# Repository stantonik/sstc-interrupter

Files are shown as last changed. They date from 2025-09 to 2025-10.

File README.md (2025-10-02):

# SSTC-Interrupter

> Digital interrupter for driving SSTC/DRSSTC Tesla coils, built around the ESP32-S3.
Easily customizable and extensible thanks to the microcontroller platform.

**Actually in development!**

## Overview

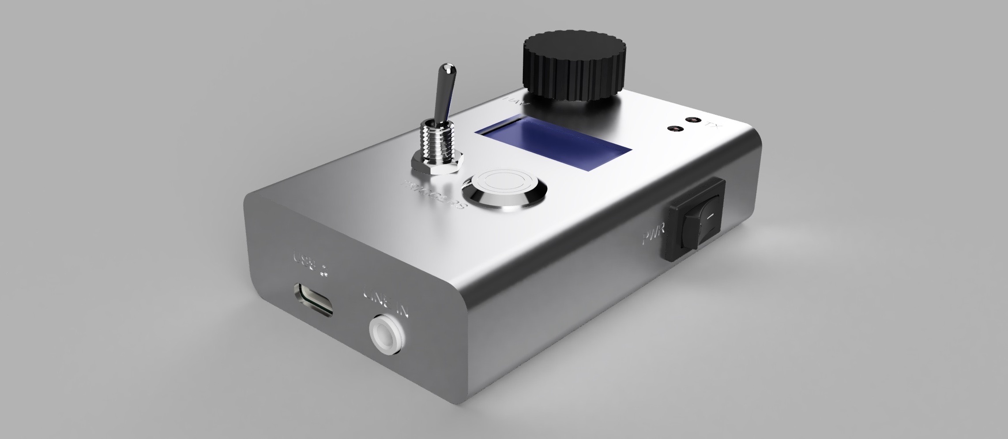
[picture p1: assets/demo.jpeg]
demo


This project implements a digital interrupter for Solid State Tesla Coils (SSTC) or Dual-Resonant SSTCs (DRSSTC). The interrupter allows precise control over the arc output using different control modes, making it easy to experiment with pulse timing, audio modulation, or MIDI control.

## Hardware Highlights

- Microcontroller: ESP32-S3 - powerful, friendly SDK, and USB-OTG.
- Isolation: Fiber-optic input using TOSLINK transceivers. Safe and affordable alternative to Broadcom HFBR14xx/24xx.
- Cost-effective: Total BOM under 20 €, including ESP32-S3, TOSLINK modules, and basic passive components.
- User interface: 164×64 OLED screen (running LVGL) with rotary encoder.
- Connectivity:
  - 3.5 mm line-in for audio modulation.
  - USB-OTG (serial, MIDI, ...)
  - TOSLINK/pin header outputs

## Features

**1. Manual Mode**

- Control three parameters directly using knobs:
  - Pulse Duration (PD) – width of each pulse.
  - Pulse Repetition Frequency (PRF) – pulse frequency.
  - Power – proportional to PD.
- Generates PWM signals from 1 Hz up to 20 kHz with a minimum pulse width of 1 µs.
- Ideal for manual experimentation and tuning the arc.WM carrier frequency is 30KHz by default, but you can adjust these value to fit your needs.

The signal generated is supposed to be ANDed with your main Tesla drive signal.

**2. Audio (Line-In) Mode**

- Connect any audio source via a 3.5 mm jack.
- Audio is sampled at 16 kHz and used to modulate the PWM output.
- Default PWM carrier frequency is 30 kHz, adjustable to match your Tesla coil system.
- Supports basic PWM modulation for now, but can be extended for other modulation schemes.

**3. MIDI Mode**

- Connect a MIDI device to control the arc in real time.
- Map MIDI notes to pulse patterns for musical performance with your Tesla coil.

## Notes

- The output of this module is intended to be ANDed with your main Tesla coil drive signal.
- All modes are fully software-driven on the ESP32-S3, making it easy to customize, extend, or add new modulation features.

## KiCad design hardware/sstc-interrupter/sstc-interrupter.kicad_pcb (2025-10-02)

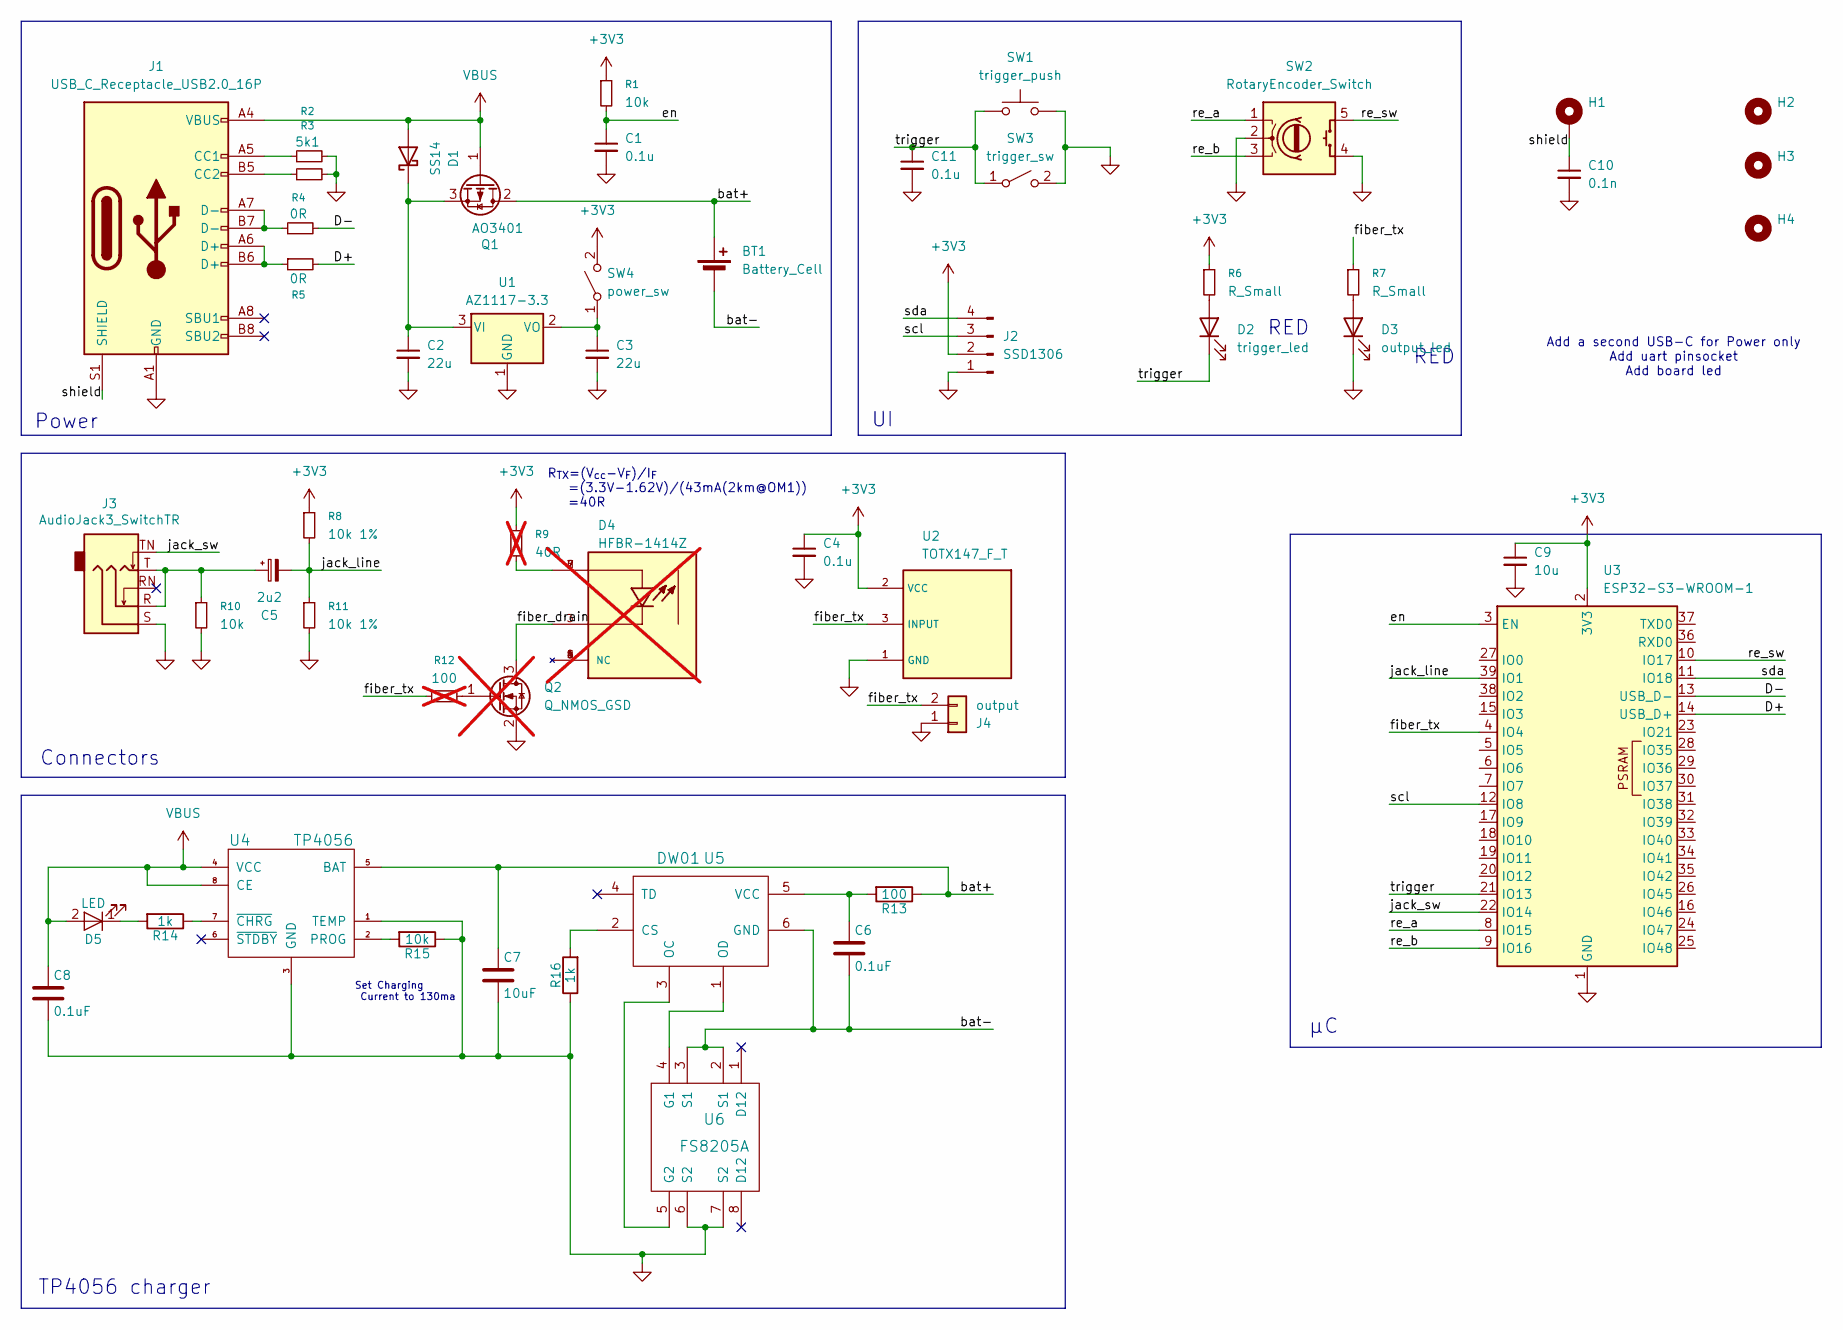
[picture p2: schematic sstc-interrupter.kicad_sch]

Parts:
BT1: Battery_Cell; JST_PH_B2B-PH-K_1x02_P2.00mm_Vertical
C1, C4, C11: 0.1u; C_0603_1608Metric_Pad1.08x0.95mm_HandSolder
C2, C3: 22u; C_0805_2012Metric_Pad1.18x1.45mm_HandSolder
C5: 2u2; C_Radial_D5.0mm_H11.0mm_P2.00mm
C6, C8: 0.1uF; C_0603_1608Metric_Pad1.08x0.95mm_HandSolder
C7: 10uF; C_0603_1608Metric_Pad1.08x0.95mm_HandSolder
C9: 10u; C_0805_2012Metric_Pad1.18x1.45mm_HandSolder
C10: 0.1n; C_0805_2012Metric_Pad1.18x1.45mm_HandSolder
D1: SS14; D_SMA
D2: trigger_led; PinHeader_1x02_P2.54mm_Vertical
D3: output_led; PinHeader_1x02_P2.54mm_Vertical
D4: HFBR-1414Z; OPTO_HFBR-1414Z; PARTREV February 15, 2019; not fitted
D5: LED; LED_0603_1608Metric_Pad1.05x0.95mm_HandSolder
H1: MountingHole_Pad; MountingHole_2.2mm_M2_DIN965_Pad
H2, H3, H4: MountingHole; MountingHole_2.2mm_M2_DIN965
J1: USB_C_Receptacle_USB2.0_16P; USB_C_Receptacle_GCT_USB4105-xx-A_16P_TopMnt_Horizontal
J2: SSD1306; PinHeader_1x04_P2.54mm_Vertical
J3: AudioJack3_SwitchTR; Jack_3.5mm_CUI_SJ1-3525N_Horizontal
J4: output; PinHeader_1x02_P2.54mm_Horizontal
Q1: AO3401; SOT-23_Handsoldering
Q2: Q_NMOS_GSD; SOT-23-3; not fitted
R1, R10, R15: 10k; R_0603_1608Metric_Pad0.98x0.95mm_HandSolder
R2, R3: 5k1; R_0603_1608Metric_Pad0.98x0.95mm_HandSolder
R4, R5: 0R; R_0603_1608Metric_Pad0.98x0.95mm_HandSolder
R6, R7: R_Small; R_0603_1608Metric_Pad0.98x0.95mm_HandSolder
R8, R11: 10k 1%; R_0603_1608Metric_Pad0.98x0.95mm_HandSolder
R9: 40R; R_0603_1608Metric_Pad0.98x0.95mm_HandSolder; not fitted
R12: 100; R_0603_1608Metric_Pad0.98x0.95mm_HandSolder; not fitted
R13: 100; R_0603_1608Metric_Pad0.98x0.95mm_HandSolder
R14, R16: 1k; R_0603_1608Metric_Pad0.98x0.95mm_HandSolder
SW1: trigger_push; PinHeader_1x02_P2.54mm_Vertical
SW2: RotaryEncoder_Switch; PinHeader_1x05_P2.54mm_Vertical
SW3: trigger_sw; PinHeader_1x02_P2.54mm_Vertical
SW4: power_sw; PinHeader_1x02_P2.54mm_Vertical
U1: AZ1117-3.3; SOT-89-3
U2: TOTX147_F_T; TOSHIBA_TORX147_F_T_
U3: ESP32-S3-WROOM-1; ESP32-S3-WROOM-1U
U4: TP4056; SOP-8_3.9x4.9mm_P1.27mm
U5: DW01; SOT-23-6_Handsoldering
U6: FS8205A; TSSOP-8_4.4x3mm_P0.65mm

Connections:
+3V3: C4.1, C9.1, J2.2, R1.1, R6.1, R8.1, R9.1, SW4.2 (B), U2.2 (VCC), U3.2 (3V3)
/D+: R5.2, U3.14 (USB_D+)
/D-: R4.2, U3.13 (USB_D-)
/bat+: BT1.1 (+), C7.1, Q1.2 (D), R13.1, U4.5 (BAT)
/bat-: BT1.2 (-), C6.2, U5.6 (GND), U6.2 (S1), U6.3 (S1)
/en: C1.1, R1.2, U3.3 (EN)
/fiber_tx: J4.2, R7.1, R12.1, U2.3 (INPUT), U3.4 (IO4)
/jack_line: C5.2, R8.2, R11.1, U3.39 (IO1)
/jack_sw: J3.TN, U3.22 (IO14)
/re_a: SW2.1 (A), U3.8 (IO15)
/re_b: SW2.3 (B), U3.9 (IO16)
/re_sw: SW2.5 (S1), U3.10 (IO17)
/scl: J2.3, U3.12 (IO8)
/sda: J2.4, U3.11 (IO18)
/shield: C10.1, H1.1, J1.S1 (SHIELD)
/trigger: C11.1, D2.1 (K), SW1.1, SW3.1 (A), U3.21 (IO13)
GND: C1.2, C2.2, C3.2, C4.2, C7.2, C8.2, C9.2, C10.2, C11.2, D3.1 (K), J1.A1 (GND), J1.A12 (GND), J1.B1 (GND), J1.B12 (GND), J2.1, J3.S, J4.1, Q2.2 (S), R2.2, R3.2, R10.2, R11.2, R15.1, R16.1, SW1.2, SW2.2 (C), SW2.4 (S2), SW3.2 (B), U1.1 (GND), U2.1 (GND), U3.1 (GND), U3.40 (GND), U3.41 (GND), U4.1 (TEMP), U4.3 (GND), U6.6 (S2), U6.7 (S2)
unnamed: C5.1, J3.R, J3.T, R10.1
unnamed: C2.1, D1.1 (K), Q1.3 (S), U1.3 (VI)
unnamed: D2.2 (A), R6.2
unnamed: D3.2 (A), R7.2
unnamed: D4.1 (NC), D4.4 (NC), D4.5 (NC), D4.8 (NC)
unnamed: D4.2, D4.6, D4.7, R9.2
unnamed: D4.3, Q2.3 (D)
unnamed: D5.1 (K), R14.2
unnamed: J1.A5 (CC1), R2.1
unnamed: J1.B5 (CC2), R3.1
unnamed: J1.A6 (D+), J1.B6 (D+), R5.1
unnamed: J1.A7 (D-), J1.B7 (D-), R4.1
unnamed: Q2.1 (G), R12.2
unnamed: C3.1, SW4.1 (A), U1.2 (VO)
unnamed: R15.2, U4.2 (PROG)
unnamed: R14.1, U4.7 (~CHRG)
unnamed: R16.2, U5.2 (CS)
unnamed: U5.3 (OC), U6.5 (G2)
unnamed: U5.1 (OD), U6.4 (G1)
unnamed: C6.1, R13.2, U5.5 (VCC)
VBUS: C8.1, D1.2 (A), D5.2 (A), J1.A4 (VBUS), J1.A9 (VBUS), J1.B4 (VBUS), J1.B9 (VBUS), Q1.1 (G), U4.4 (VCC), U4.8 (CE)

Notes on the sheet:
Add a second USB-C for Power only Add uart pinsocket Add board led
Set Charging Current to 130ma
Connectors
R_{TX}=(V_{cc}-V_{F})/I_{F} =(3.3V-1.62V)/(43mA(2km@OM1)) =40R
RED
Power
TP4056 charger

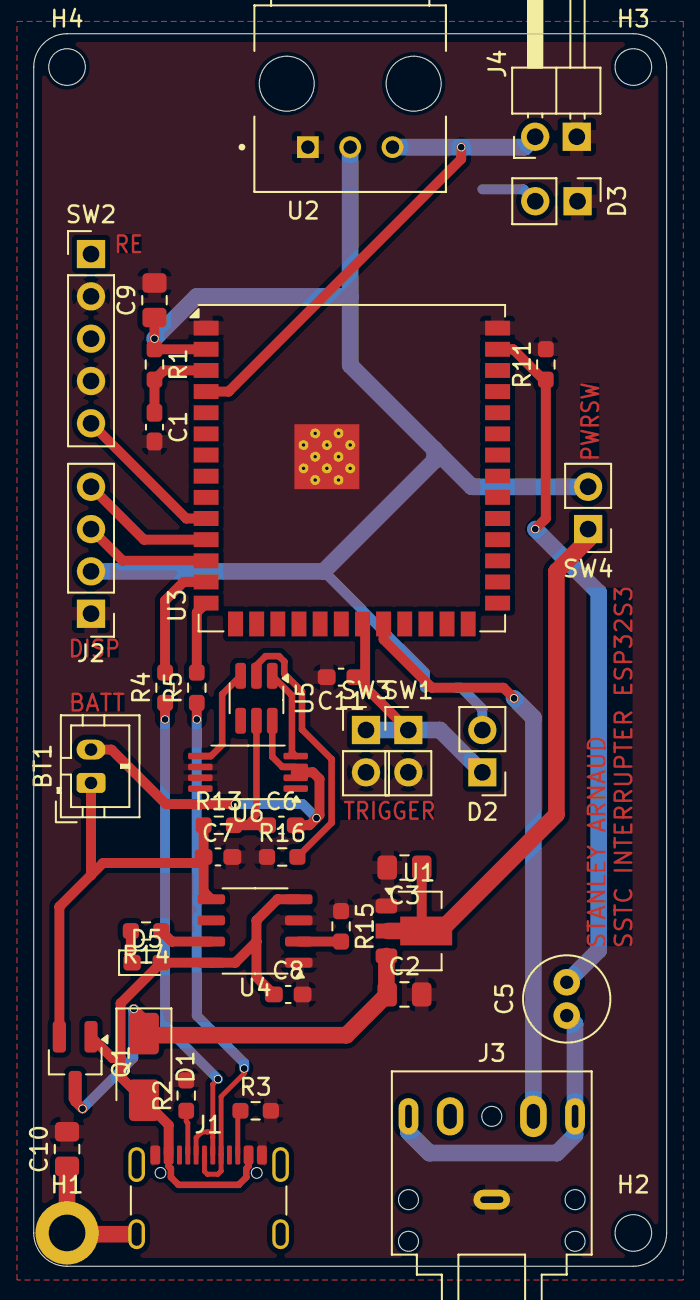
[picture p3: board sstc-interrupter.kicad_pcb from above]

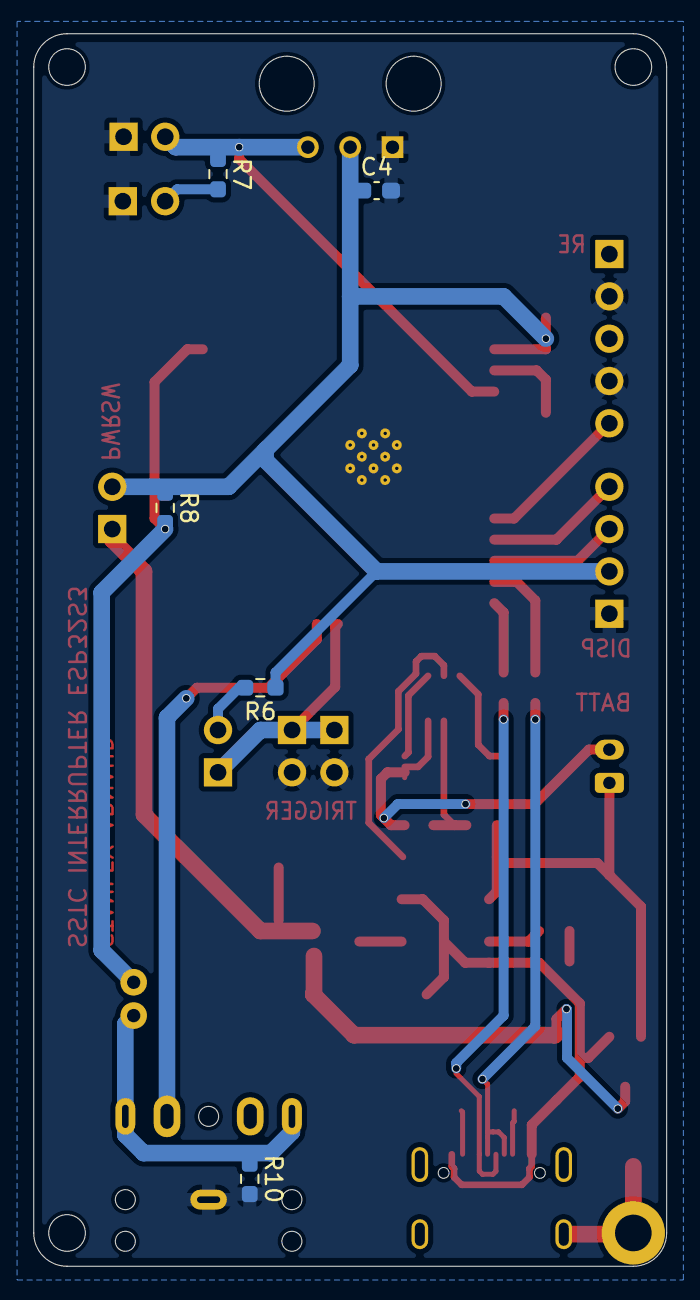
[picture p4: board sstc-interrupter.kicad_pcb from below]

Board: 2 copper layers, 38.0 x 74.0 mm, 49 parts (5 on the bottom side), 34 nets.

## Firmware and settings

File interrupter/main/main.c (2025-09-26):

/*
 * Copyright (C) 2025 Stanley Arnaud <stantonik@stantonik-mba.local>
 *
 * Distributed under terms of the MIT license.
 */

#include "button_gpio.h"
#include "esp_log.h"
#include "iot_button.h"
#include "menu.h"
#include "pwm.h"
#include <stdbool.h>
#include <stdint.h>

#define PIN_TRIGGER CONFIG_INTERRUPT_PIN_TRIGGER
#define PIN_JACK_SW CONFIG_INTERRUPT_PIN_JACK_SW

#define TAG "interrupter"

button_handle_t trigger_btn = NULL;
button_handle_t jack_btn = NULL;

static void button_down_cb(void *arg, void *usr_data)
{
    button_handle_t btn = (button_handle_t)arg;

    if (btn == trigger_btn)
    {
        ESP_LOGI(TAG, "Trigger button pressed → Armed");
        pwm_arm();
    }
    else if (btn == jack_btn)
    {
        ESP_LOGI(TAG, "Jack button pressed → Audio mode");
        pwm_set_mode(PWM_AUDIO);
    }
}

static void button_up_cb(void *arg, void *usr_data)
{
    button_handle_t btn = (button_handle_t)arg;

    if (btn == trigger_btn)
    {
        ESP_LOGI(TAG, "Trigger button released → Disarmed");
        pwm_disarm();
    }
    else if (btn == jack_btn)
    {
        ESP_LOGI(TAG, "Jack button released → Manual mode");
        pwm_set_mode(PWM_MANUAL);
    }
}

void app_main(void)
{
    menu_init();
    pwm_init();
    pwm_set_mode(PWM_MANUAL);

    button_config_t btn_cfg = {0};

    button_gpio_config_t trigger_gpio_cfg = {
        .gpio_num = PIN_TRIGGER,
        .active_level = 0,
    };
    iot_button_new_gpio_device(&btn_cfg, &trigger_gpio_cfg, &trigger_btn);

    button_gpio_config_t jack_gpio_cfg = {
        .gpio_num = PIN_JACK_SW,
        .active_level = 0,
    };
    iot_button_new_gpio_device(&btn_cfg, &jack_gpio_cfg, &jack_btn);

    iot_button_register_cb(trigger_btn, BUTTON_PRESS_DOWN, NULL, button_down_cb,
                           (void *)trigger_btn);
    iot_button_register_cb(trigger_btn, BUTTON_PRESS_UP, NULL, button_up_cb,
                           (void *)trigger_btn);

    iot_button_register_cb(jack_btn, BUTTON_PRESS_DOWN, NULL, button_down_cb,
                           (void *)jack_btn);
    iot_button_register_cb(jack_btn, BUTTON_PRESS_UP, NULL, button_up_cb,
                           (void *)jack_btn);
}

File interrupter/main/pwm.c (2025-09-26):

/*
 * Copyright (C) 2025 Stanley Arnaud <stantonik@stantonik-mba.local>
 *
 * Distributed under terms of the MIT license.
 */

/**
 * @file pwm.c
 * @brief
 *
 * @author Stanley Arnaud
 * @date 09/26/2025
 * @version 0
 */

// -----------------------------------------------------------------------------
// Includes
// -----------------------------------------------------------------------------
#include "pwm.h"
#include "audio.h"
#include "driver/ledc.h"
#include "driver/rmt.h"
#include "rom/gpio.h"
#include "sdkconfig.h"
#include "soc/gpio_reg.h"
#include "soc/gpio_sig_map.h"

// -----------------------------------------------------------------------------
// Macros and Constants
// -----------------------------------------------------------------------------
#define PIN_OUTPUT CONFIG_INTERRUPT_PIN_OUTPUT

#define RMT_CHANNEL RMT_CHANNEL_0
#define RMT_CLK_DIV 80 // 80 MHz / 80 = 1 MHz → 1 tick = 1 us
#define RMT_TICK_US (80 / RMT_CLK_DIV)

#define LEDC_TIMER LEDC_TIMER_0
#define LEDC_MODE LEDC_LOW_SPEED_MODE
#define LEDC_CHANNEL LEDC_CHANNEL_0
#define LEDC_DUTY_RES LEDC_TIMER_8_BIT
#define LEDC_FREQUENCY (30e3)

#define TAG "pwm"

// -----------------------------------------------------------------------------
// Static Variables
// -----------------------------------------------------------------------------
static pwm_mode_t mode = PWM_MANUAL;
static QueueHandle_t lpwm_task_queue = NULL;
static TaskHandle_t lpwm_task_handle = NULL;
static bool armed = false;

// -----------------------------------------------------------------------------
// Static Function Declarations
// -----------------------------------------------------------------------------

// -----------------------------------------------------------------------------
// Static Function Definitions
// -----------------------------------------------------------------------------
static void lpwm_task(void *pvParams)
{
    uint32_t period_tick = 0;
    uint32_t pulse_width_tick = 0;
    uint32_t pwm_data[2];

    while (1)
    {
        // Try to receive new PWM data (non-blocking)
        if (xQueueReceive(lpwm_task_queue, &pwm_data, 0) == pdPASS)
        {
            period_tick = pwm_data[0];
            pulse_width_tick = pwm_data[1];
        }

        // If period or pulse_width is zero, block until valid value arrives
        while (period_tick == 0 || pulse_width_tick == 0)
        {
            // Ensure output pin is low
            WRITE_PERI_REG(GPIO_OUT_W1TC_REG, (1ULL << PIN_OUTPUT));

            // Wait for new PWM data
            if (xQueueReceive(lpwm_task_queue, &pwm_data, portMAX_DELAY) ==
                pdPASS)
            {
                period_tick = pwm_data[0];
                pulse_width_tick = pwm_data[1];
            }
        }

        rmt_item32_t item;
        item.level0 = 1;
        item.duration0 = pulse_width_tick; // high time
        item.level1 = 0;
        item.duration1 = pulse_width_tick; // low time

        rmt_write_items(RMT_CHANNEL, &item, 1, false);
        vTaskDelay(pdMS_TO_TICKS((period_tick * RMT_TICK_US) / 1000));
    }
}

static void pwm_ledc_set_duty(uint8_t duty)
{
    // if (duty > 512) duty = 512;
    ESP_ERROR_CHECK(ledc_set_duty(LEDC_MODE, LEDC_CHANNEL, duty));
    ESP_ERROR_CHECK(ledc_update_duty(LEDC_MODE, LEDC_CHANNEL));
}

// -----------------------------------------------------------------------------
// Function Definitions
// -----------------------------------------------------------------------------
void pwm_init(void)
{
    lpwm_task_queue = xQueueCreate(2, sizeof(uint32_t[2]));

    ledc_channel_config_t ledc_channel = {.speed_mode = LEDC_MODE,
                                          .channel = LEDC_CHANNEL,
                                          .timer_sel = LEDC_TIMER,
                                          .intr_type = LEDC_INTR_DISABLE,
                                          .gpio_num = PIN_OUTPUT,
                                          .duty = 0,
                                          .hpoint = 0};
    ESP_ERROR_CHECK(ledc_channel_config(&ledc_channel));

    rmt_config_t config = {
        .rmt_mode = RMT_MODE_TX,
        .channel = RMT_CHANNEL,
        .gpio_num = PIN_OUTPUT,
        .clk_div = RMT_CLK_DIV,
        .mem_block_num = 1,
        .tx_config.loop_en = true,
        .tx_config.carrier_en = false,
    };
    rmt_config(&config);
    rmt_driver_install(config.channel, 0, 0);

    xTaskCreate(lpwm_task, "low_pwm_task", 1024, NULL, 2, &lpwm_task_handle);

    audio_init();
    audio_set_pwm_duty_update_cb(pwm_ledc_set_duty);
    // Prepare and then apply the LEDC PWM timer configuration
    ledc_timer_config_t ledc_timer = {.speed_mode = LEDC_MODE,
                                      .duty_resolution = LEDC_DUTY_RES,
                                      .timer_num = LEDC_TIMER,
                                      .freq_hz = LEDC_FREQUENCY,
                                      .clk_cfg = LEDC_AUTO_CLK};
    ESP_ERROR_CHECK(ledc_timer_config(&ledc_timer));

    pwm_disarm();
}

void pwm_arm(void)
{
    armed = true;
    if (mode == PWM_MANUAL)
    {
        gpio_matrix_out(PIN_OUTPUT, RMT_SIG_OUT0_IDX, 0, 0);
    }
    else if (mode == PWM_AUDIO)
    {
        gpio_matrix_out(PIN_OUTPUT, LEDC_LS_SIG_OUT0_IDX, 0, 0);
    }
}

void pwm_disarm(void)
{
    armed = false;
    gpio_matrix_out(PIN_OUTPUT, SIG_GPIO_OUT_IDX, 0, 0);
}

void pwm_set_mode(pwm_mode_t pwm_mode)
{
    if (pwm_mode == PWM_AUDIO)
    {
        if (mode == PWM_AUDIO) return;

        // Stop MANUAL
        vTaskSuspend(lpwm_task_handle);
        rmt_tx_stop(RMT_CHANNEL);
        WRITE_PERI_REG(GPIO_OUT_W1TC_REG, (1ULL << PIN_OUTPUT));

        // Start AUDIO
        if (armed) gpio_matrix_out(PIN_OUTPUT, LEDC_LS_SIG_OUT0_IDX, 0, 0);
        audio_listen();
    }
    else if (pwm_mode == PWM_MANUAL)
    {
        if (mode == PWM_MANUAL) return;

        // Stop AUDIO
        audio_stop();
        ledc_stop(LEDC_MODE, LEDC_CHANNEL_0, 0);
        WRITE_PERI_REG(GPIO_OUT_W1TC_REG, (1ULL << PIN_OUTPUT));

        // Start MANUAL
        if (armed) gpio_matrix_out(PIN_OUTPUT, RMT_SIG_OUT0_IDX, 0, 0);
        vTaskResume(lpwm_task_handle);
    }

    mode = pwm_mode;
}

pwm_mode_t pwm_get_mode(void) { return mode; }
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
